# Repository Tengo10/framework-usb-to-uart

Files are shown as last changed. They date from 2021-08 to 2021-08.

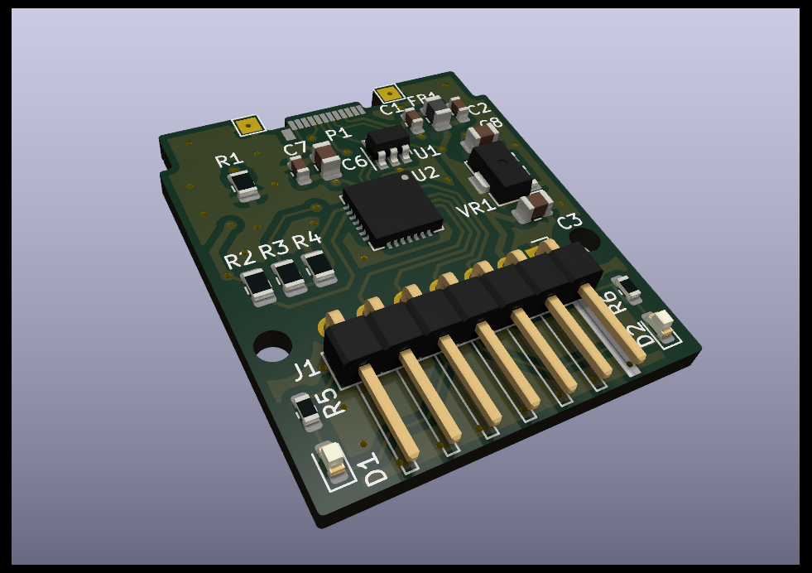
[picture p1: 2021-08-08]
src/render_v01.png

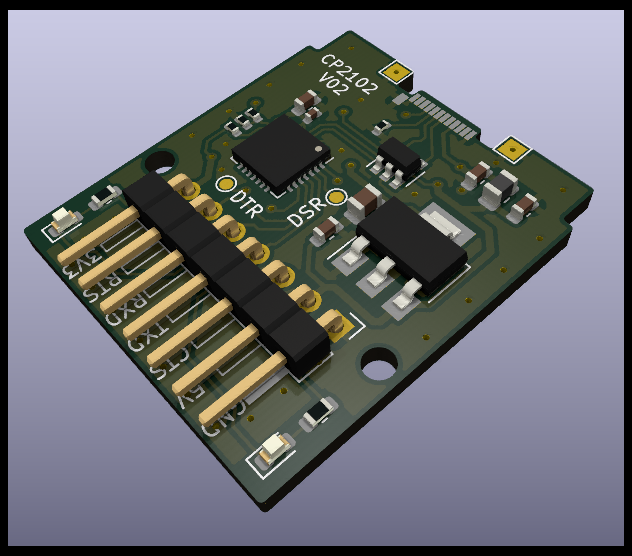
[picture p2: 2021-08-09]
src/render_v02.png

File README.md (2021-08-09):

# framework-usb-to-uart
USB to UART Expansion Card for the Framework Laptop

## Info
*Currently an early version, design untested*

A USB to UART converter based on the CP2102 chip by Silicon Labs, also includes an external 3.3V LDO for more power than the integrated on.

### Design Goals

 - almost no extended JLC SMT parts
 - no FTDI parts
 - at least 150 mA @ 3.3V

## Todo

- Do cost optimization
- find a good LDO (AMS out of stock)
- fix some SMT data

## Manufacture
Parts, PCB and Assembly at JLC PCB are about 24€ for 5 PCBs, 2 assembled.

## Legal
Based on the reference design by the Framework Team. Not responsible for anything. Design provided as is.

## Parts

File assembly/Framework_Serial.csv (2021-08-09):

Designator | Quantity | Value | Footprint | LCSC Part #
C1, C2, | 2 | 1u | Capacitor_SMD:C_0603_1608Metric | C15849
C3, | 1 | 10u | Capacitor_SMD:C_0603_1608Metric | C19702
C6, | 1 | 4.7u | Capacitor_SMD:C_0603_1608Metric | C19666
C7, | 1 | 0.1u | Capacitor_SMD:C_0402_1005Metric | C1525
C8, | 1 | 22u | Capacitor_SMD:C_0805_2012Metric | C45783
D1, | 1 | Yl | LED_SMD:LED_0603_1608Metric | C72038
D2, | 1 | Gr | LED_SMD:LED_0603_1608Metric | C72043
FB1, | 1 | 100R | Inductor_SMD:L_0805_2012Metric | C1015
H1, H2, | 2 | MountingHole | MountingHole:MountingHole_2.2mm_M2
J1, | 1 | Conn_01x07_Male | Connector_PinHeader_2.54mm:PinHeader_1x07_P2.54mm_Horizontal
P1, | 1 | USB_C_Plug_USB2.0 | Framework_Serial:USB_C_Plug_Molex_105444
R1, | 1 | 5.1K | Resistor_SMD:R_0402_1005Metric | C25905
R2, | 1 | 1k | Resistor_SMD:R_0402_1005Metric | C11702
R3, | 1 | 22.1k | Resistor_SMD:R_0402_1005Metric | C25768
R4, | 1 | 47.5k | Resistor_SMD:R_0402_1005Metric | C25792
R5, R6, | 2 | 470 | Resistor_SMD:R_0603_1608Metric | C17710
TP1, | 1 | CTS | TestPoint:TestPoint_Pad_D1.0mm
TP2, | 1 | DSR | TestPoint:TestPoint_Pad_D1.0mm
TP3, | 1 | P1 | TestPoint:TestPoint_Pad_1.5x1.5mm
TP4, | 1 | P2 | TestPoint:TestPoint_Pad_1.5x1.5mm
TP5, | 1 | P3 | TestPoint:TestPoint_Pad_1.5x1.5mm
TP6, | 1 | P4 | TestPoint:TestPoint_Pad_1.5x1.5mm
U1, | 1 | USBLC6-2SC6 | Package_TO_SOT_SMD:SOT-23-6 | C7519
U2, | 1 | CP2102N-A01-GQFN28 | Package_DFN_QFN:QFN-28-1EP_5x5mm_P0.5mm_EP3.35x3.35mm | C6568
U3, | 1 | AMS1117-3.3 | Package_TO_SOT_SMD:SOT-223-3_TabPin2 | C6186

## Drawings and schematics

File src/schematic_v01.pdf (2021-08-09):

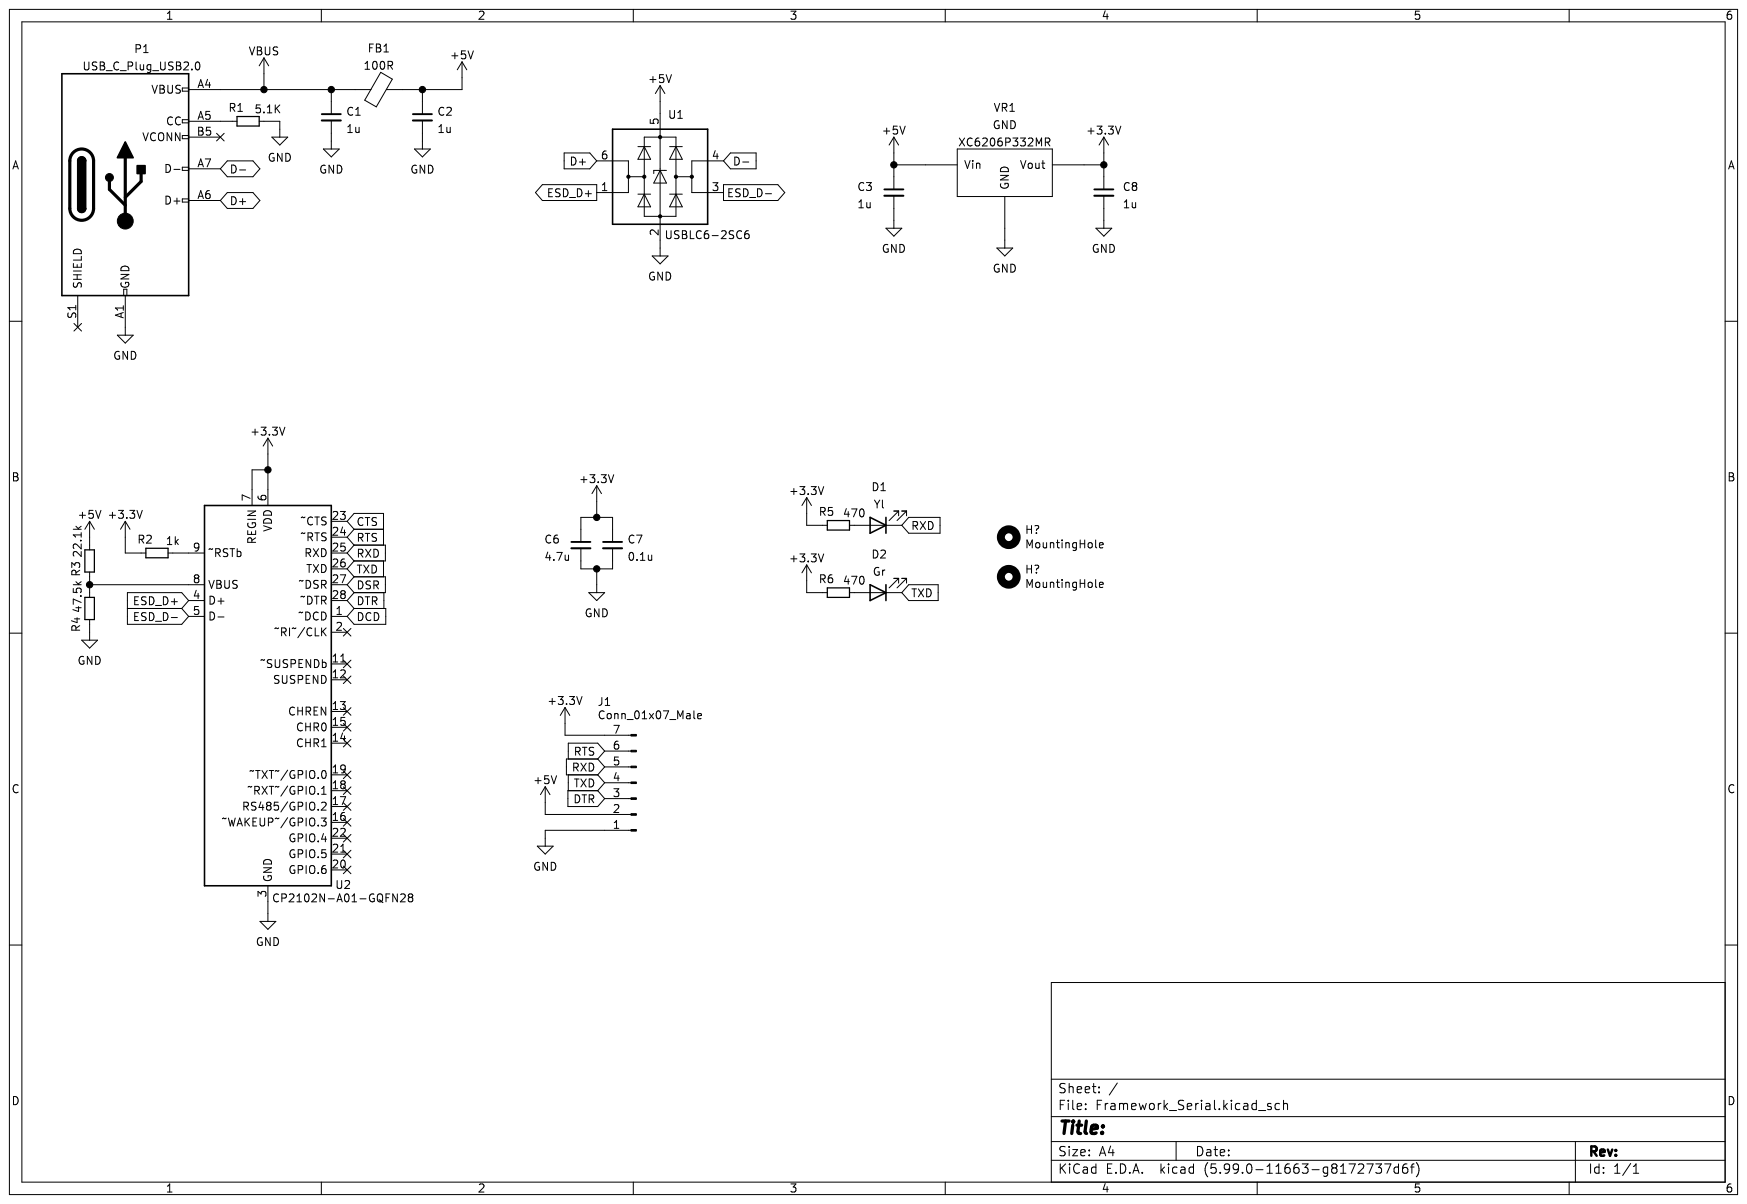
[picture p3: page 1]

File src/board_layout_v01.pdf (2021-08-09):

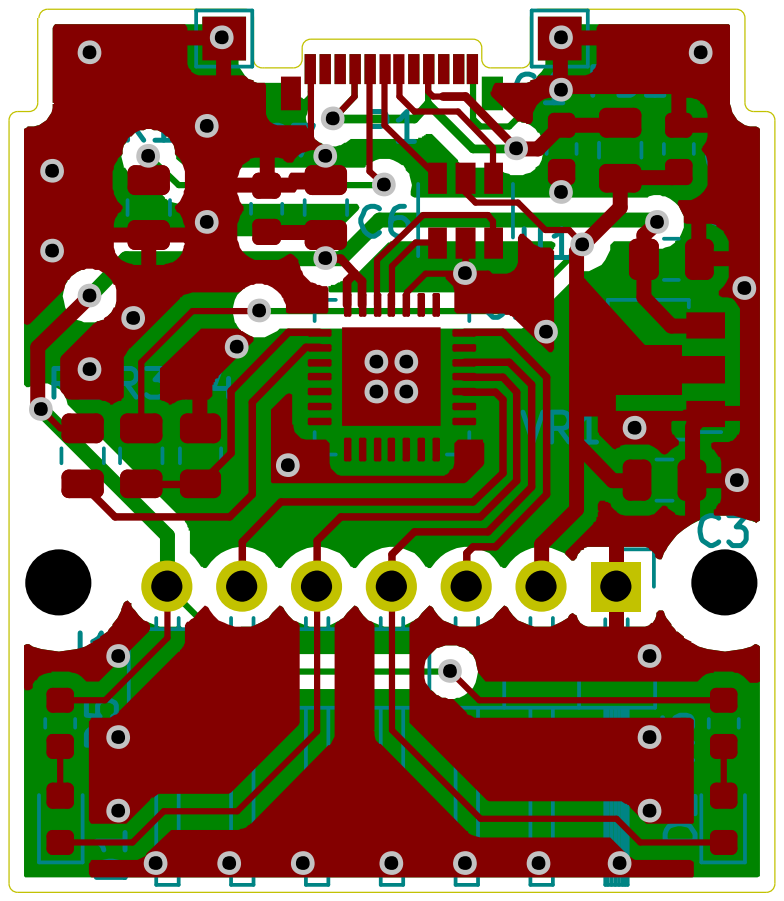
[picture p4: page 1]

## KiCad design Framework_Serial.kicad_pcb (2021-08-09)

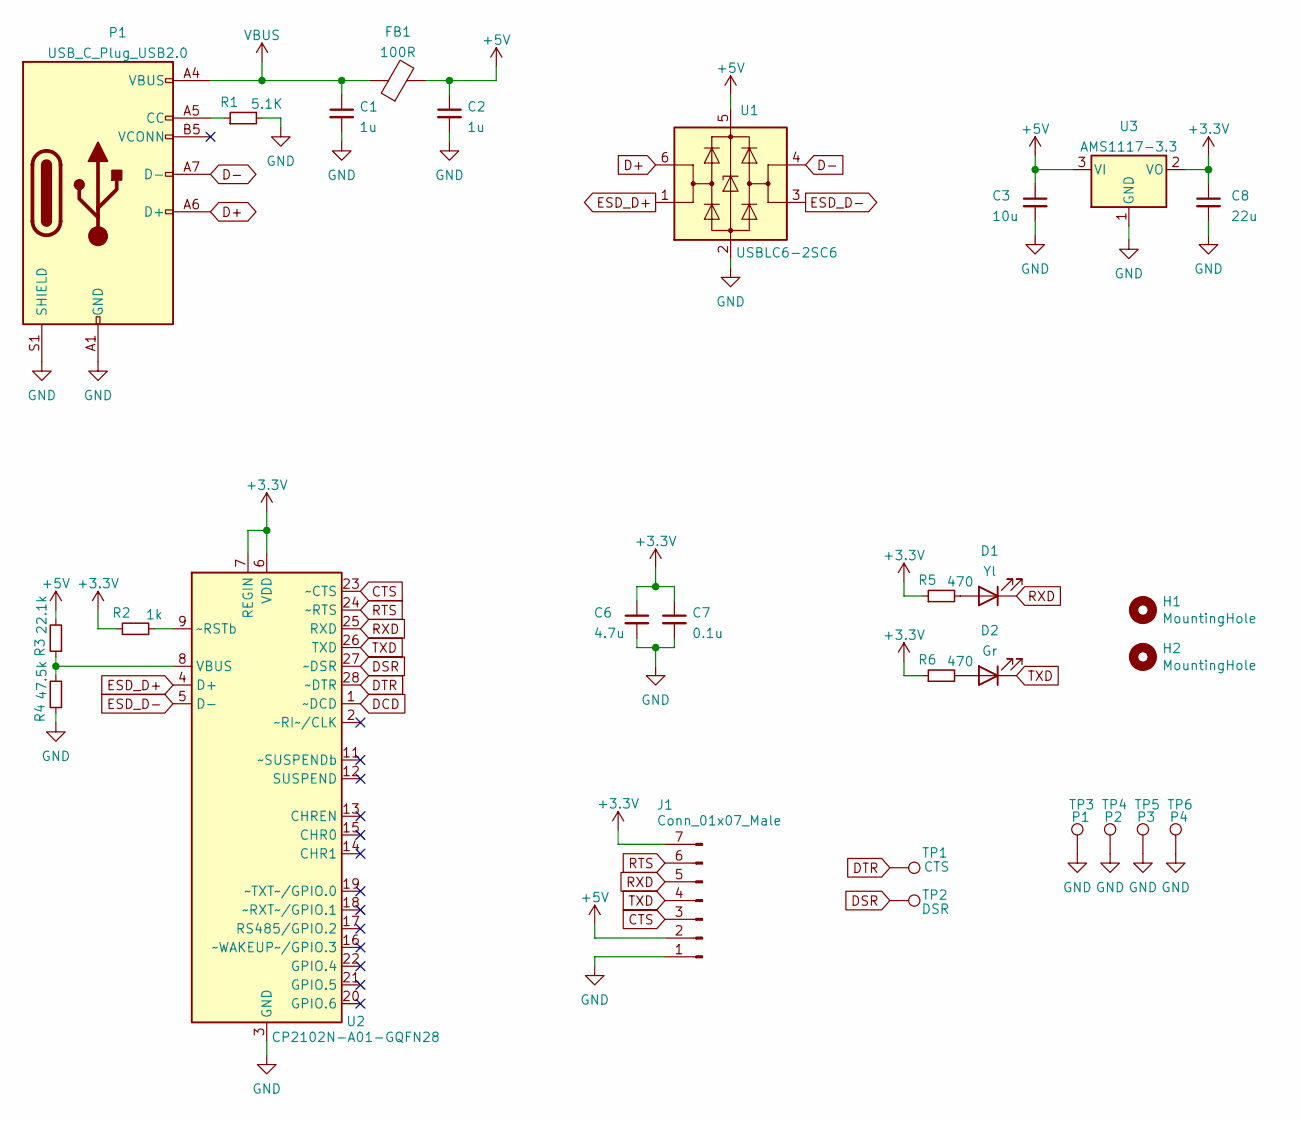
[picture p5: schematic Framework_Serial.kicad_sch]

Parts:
C1, C2: 1u; C_0603_1608Metric; LCSC Part # C15849
C3: 10u; C_0603_1608Metric; LCSC Part # C19702
C6: 4.7u; C_0603_1608Metric; LCSC Part # C19666
C7: 0.1u; C_0402_1005Metric; LCSC Part # C1525
C8: 22u; C_0805_2012Metric; LCSC Part # C45783
D1: Yl; LED_0603_1608Metric; LCSC Part # C72038
D2: Gr; LED_0603_1608Metric; LCSC Part # C72043
FB1: 100R; L_0805_2012Metric; LCSC Part # C1015
H1, H2: MountingHole; MountingHole_2.2mm_M2
J1: Conn_01x07_Male; PinHeader_1x07_P2.54mm_Horizontal
P1: USB_C_Plug_USB2.0; USB_C_Plug_Molex_105444
R1: 5.1K; R_0402_1005Metric; LCSC Part # C25905
R2: 1k; R_0402_1005Metric; LCSC Part # C11702
R3: 22.1k; R_0402_1005Metric; LCSC Part # C25768
R4: 47.5k; R_0402_1005Metric; LCSC Part # C25792
R5, R6: 470; R_0603_1608Metric; LCSC Part # C17710
TP1: CTS; TestPoint_Pad_D1.0mm
TP2: DSR; TestPoint_Pad_D1.0mm
TP3: P1; TestPoint_Pad_1.5x1.5mm
TP4: P2; TestPoint_Pad_1.5x1.5mm
TP5: P3; TestPoint_Pad_1.5x1.5mm
TP6: P4; TestPoint_Pad_1.5x1.5mm
U1: USBLC6-2SC6; SOT-23-6; LCSC Part # C7519
U2: CP2102N-A01-GQFN28; QFN-28-1EP_5x5mm_P0.5mm_EP3.35x3.35mm; LCSC Part # C6568
U3: AMS1117-3.3; SOT-223-3_TabPin2; LCSC Part # C6186

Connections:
+3V3: C6.1, C7.1, C8.1, J1.7, R2.1, R5.1, R6.1, U2.6 (VDD), U2.7 (REGIN), U3.2 (VO)
+5V: C2.1, C3.1, FB1.2, J1.2, R3.2, U1.5 (VBUS), U3.3 (VI)
CTS: J1.3, U2.23 (~CTS)
D+: P1.A6 (D+), U1.6 (I/O1)
D-: P1.A7 (D-), U1.4 (I/O2)
DCD: U2.1 (~DCD)
DSR: TP2.1, U2.27 (~DSR)
DTR: TP1.1, U2.28 (~DTR)
ESD_D+: U1.1 (I/O1), U2.4 (D+)
ESD_D-: U1.3 (I/O2), U2.5 (D-)
GND: C1.2, C2.2, C3.2, C6.2, C7.2, C8.2, J1.1, P1.A1 (GND), P1.A12 (GND), P1.B1 (GND), P1.B12 (GND), P1.S1 (SHIELD), R1.2, R4.1, TP3.1, TP4.1, TP5.1, TP6.1, U1.2 (GND), U2.3 (GND), U2.29 (GND), U3.1 (GND)
unnamed: D1.2 (A), R5.2
unnamed: D2.2 (A), R6.2
unnamed: P1.A5 (CC), R1.1
unnamed: R2.2, U2.9 (~RSTb)
unnamed: R3.1, R4.2, U2.8 (VBUS)
RTS: J1.6, U2.24 (~RTS)
RXD: D1.1 (K), J1.5, U2.25 (RXD)
TXD: D2.1 (K), J1.4, U2.26 (TXD)
VBUS: C1.1, FB1.1, P1.A4 (VBUS), P1.A9 (VBUS), P1.B4 (VBUS), P1.B9 (VBUS)

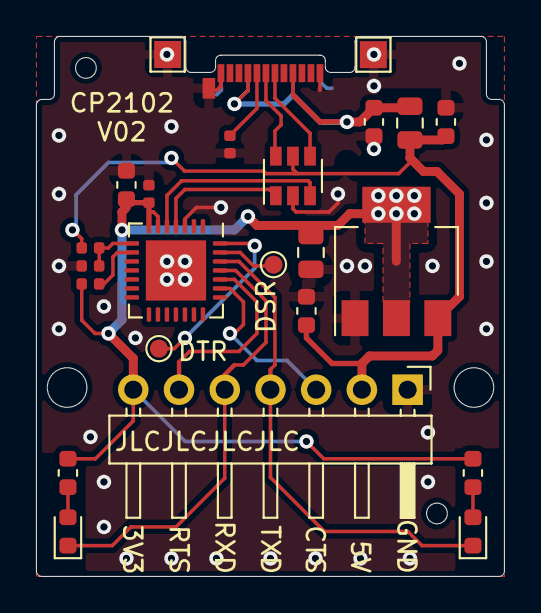
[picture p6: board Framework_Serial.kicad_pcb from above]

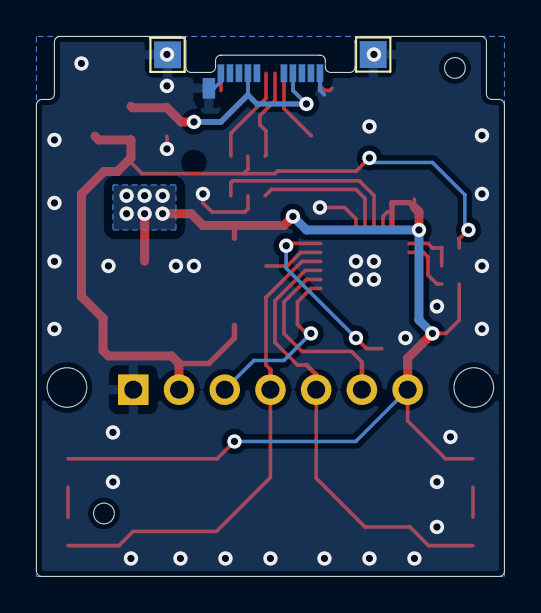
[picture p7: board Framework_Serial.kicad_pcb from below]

Board: 2 copper layers, 26.0 x 30.0 mm, 28 parts (2 on the bottom side), 19 nets.

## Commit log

2021-08-08 Add files via upload
    added initial design file version
    [Framework_Serial.kicad_pcb, Framework_Serial.kicad_sch]
2021-08-08 added pcb render
2021-08-09 BOM and placement files
    [Framework_Serial.csv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]
2021-08-09 added gerber files of V02
    [Framework_Serial-B_Cu.gbr, Framework_Serial-B_Mask.gbr, Framework_Serial-B_Paste.gbr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]
2021-08-09 moved components around: v02
    [Framework_Serial.kicad_pcb]
2021-08-09 added testpoints, changed to AMS1117-3.3
    [Framework_Serial.kicad_sch]
2021-08-09 removed unnecessary Vias
    [Framework_Serial.kicad_pcb]
2021-08-09 changed LCSC parts number for LED resistor
    [Framework_Serial.kicad_sch]
